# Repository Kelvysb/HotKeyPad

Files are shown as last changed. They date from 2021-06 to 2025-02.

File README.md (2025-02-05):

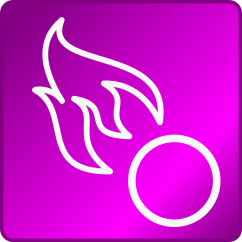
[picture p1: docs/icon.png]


# HotKeyPad

Arduino based hot keys programmable mini keyboard.

Arduino **Mega32U4** based.

# 

# Serial commands

* Ack 
  - Command = A
* Set a command 
  - Command = S\<pos\>\<command\>
  - pos = 48 to 59 (11 buttons, ASCII {0,1,2,3,4,5,6,7,8,9,:,;})
* Read command list 
  - command = R
* Clear memmory 
  - command = C

# Command format

```
<mode><hold time><delay time><ctrl><alt><shift><gui>[<key list>]
```

* mode:
  * 48 = hold (press all keys)
  * 49 = sequence (press keys in sequence)
* hold time:
  * Time holding the key, (t * 100)ms (modifiers not included) 
  * only on sequence mode
* delay time:
  * Time between the keys, (t * 100)ms (modifiers not included) 
  * only on sequence mode
* crtl, alt, shift, and gui (modifiers)
  * 48 = not pressed
  * 49 = pressed
* key list
  * Key sequence (ASCII code)
  * In hold mode pressed all at the same time, and released when the button it's released.
  * In sequence mode press and release using hold and delay times.

## Control Keys

| KEY HEXADECIMAL | VALUE | DECIMAL VALUE |
| --- | ----- | --- |
| KEY_LEFT_CTRL | 0x80  | 128 |
| KEY_LEFT_SHIFT  | 0x81  | 129 |
| KEY_LEFT_ALT | 0x82  | 130 |
| KEY_LEFT_GUI | 0x83  | 131 |
| KEY_RIGHT_CTRL  | 0x84  | 132 |
| KEY_RIGHT_SHIFT | 0x85  | 133 |
| KEY_RIGHT_ALT | 0x86  | 134 |
| KEY_RIGHT_GUI | 0x87  | 135 |
| KEY_UP_ARROW | 0xDA  | 218 |
| KEY_DOWN_ARROW  | 0xD9  | 217 |
| KEY_LEFT_ARROW  | 0xD8  | 216 |
| KEY_RIGHT_ARROW | 0xD7  | 215 |
| KEY_BACKSPACE | 0xB2  | 178 |
| KEY_TAB | 0xB3  | 179 |
| KEY_RETURN | 0xB0  | 176 |
| KEY_ESC | 0xB1  | 177 |
| KEY_INSERT | 0xD1  | 209 |
| KEY_DELETE | 0xD4  | 212 |
| KEY_PAGE_UP | 0xD3  | 211 |
| KEY_PAGE_DOWN | 0xD6  | 214 |
| KEY_HOME | 0xD2  | 210 |
| KEY_END | 0xD5  | 213 |
| KEY_CAPS_LOCK | 0xC1  | 193 |
| KEY_F1 | 0xC2  | 194 |
| KEY_F2 | 0xC3  | 195 |
| KEY_F3 | 0xC4  | 196 |
| KEY_F4 | 0xC5  | 197 |
| KEY_F5 | 0xC6  | 198 |
| KEY_F6 | 0xC7  | 199 |
| KEY_F7 | 0xC8  | 200 |
| KEY_F8 | 0xC9  | 201 |
| KEY_F9 | 0xCA  | 202 |
| KEY_F10 | 0xCB  | 203 |
| KEY_F11 | 0xCC  | 204 |
| KEY_F12 | 0xCD  | 205 |
| KEY_F13 | 0xF0  | 240 |
| KEY_F14 | 0xF1  | 241 |
| KEY_F15 | 0xF2  | 242 |
| KEY_F16 | 0xF3  | 243 |
| KEY_F17 | 0xF4  | 244 |
| KEY_F18 | 0xF5  | 245 |
| KEY_F19 | 0xF6  | 246 |
| KEY_F20 | 0xF7  | 247 |
| KEY_F21 | 0xF8  | 248 |
| KEY_F22 | 0xF9  | 249 |
| KEY_F23 | 0xFA  | 250 |
| KEY_F24 | 0xFB  | 251 |

# Program

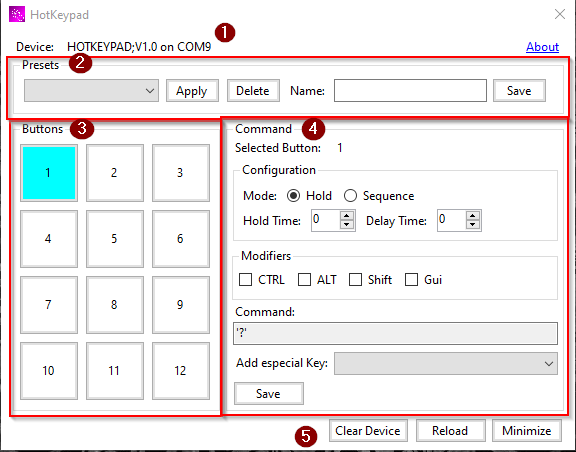
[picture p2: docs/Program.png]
Program


1. This field indicates the connected device and the port;
2. Presets:
   * Here you can save presets, when a preset it's applied, the memory of the device it's cleared and all the commands of the preset it's loaded to the device;
3. The buttons of the device, you can select they to alter it's configurations;
4. Button configuration you can set what a button will do here:
   * Mode:
     - hold, all buttons will be pressed at the same time;
     - sequence, the button will be pressed in sequence following the configured 'hold time' and 'delay time' (time to wait before press the next button);
   * Modifiers: 
     - Control, alt, Shift, and Gui (win key on windows);
   * Command:
     - Just press a key to set, and use backspace to remove a key
     - To add a especial key/command use the list bellow.
   * Save: 
     - Remember to save to record the command on the device.
5. Controls:
   * Clear Device:
     - Clear device memory;
     - Reload commands from the connected device;
     - Minimize to tray;

# Presets

* Presets are saved on `<Your Document Folder>\HotKeyPad` on '*json*' format.
* You can export presets copying them from this folder.
* You can import presets adding them to this folder.

# Casing (3D printed) Version 2.0 - Using switches

[Model on Thingiverse](https://www.thingiverse.com/thing:6915041)

3D printed Casing
3D printed Casing
3D printed Casing
3D printed Casing
3D printed Casing

# Base Circuit 2.0

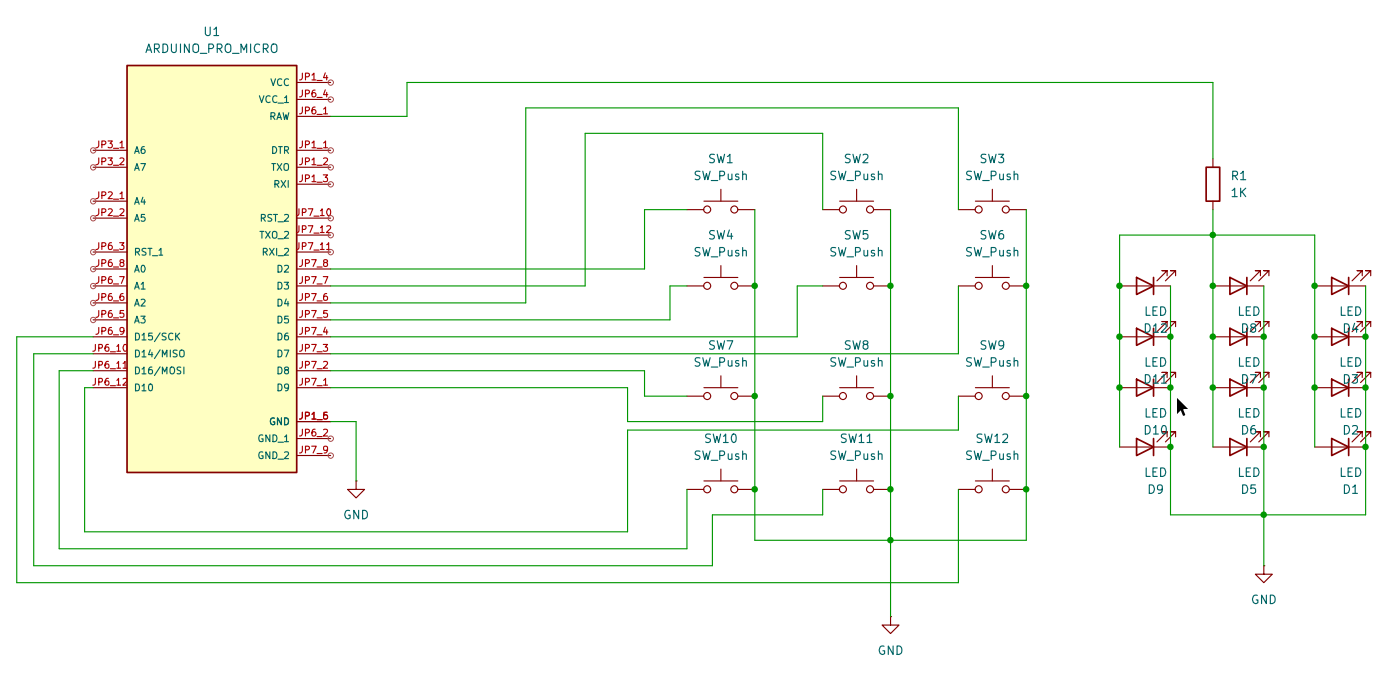
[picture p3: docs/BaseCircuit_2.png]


# Material List 2.0

- Arduino Pro Micro (Mega32U4):
  
  - [Aliexpress: Arduino pro micro](https://s.click.aliexpress.com/e/_oDuboil);

- Keypad:
  
  - 12 keyboard switchs;
    - [Aliexpress Switches](https://s.click.aliexpress.com/e/_oD1yDoz)
  - 12 Keycaps (can be printed, files included)
  - 12 3mm leds
  - 24 Stamped contacts (removed from commom stamped IC sockets)
    - [Aliexpress stamped sockets](https://s.click.aliexpress.com/e/_oBNMCW9)

- Wires for assembly;

- Soldering wire;

- USB cable;

- 4 M3 Bolts;

- 4 M3 Nuts;

- A good soldering iron;

- Patience;

# 

# Base Circuit 1.0

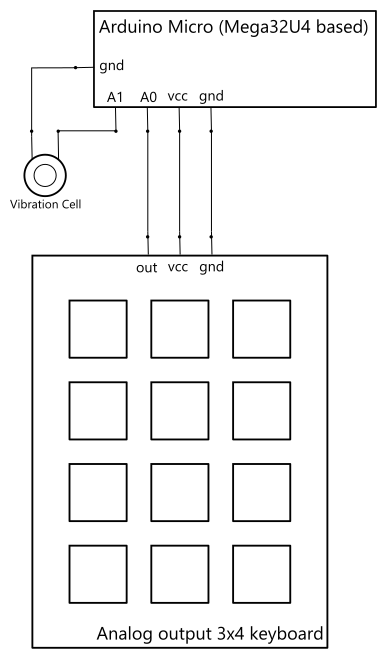
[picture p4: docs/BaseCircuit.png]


- Vibration cell optional.
- Keyboard can be of any kind, only need to update '*readButton*' method on Arduino code (*\Arduino\HotKeyPad\HotKeyPad.ino*)

# Casing (3D printed) Version 1.0 - Using resistive 3x4 Keypad

[Model on Thingiverse](https://www.thingiverse.com/thing:5168905)

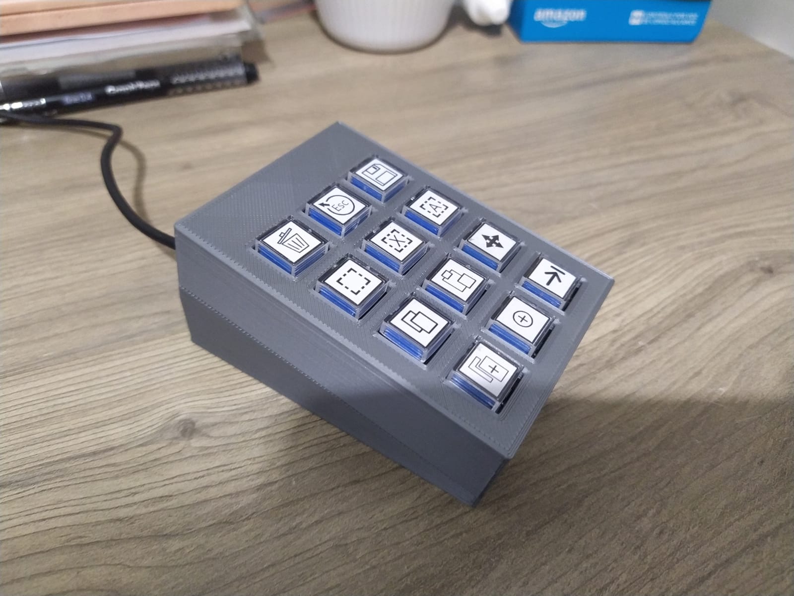
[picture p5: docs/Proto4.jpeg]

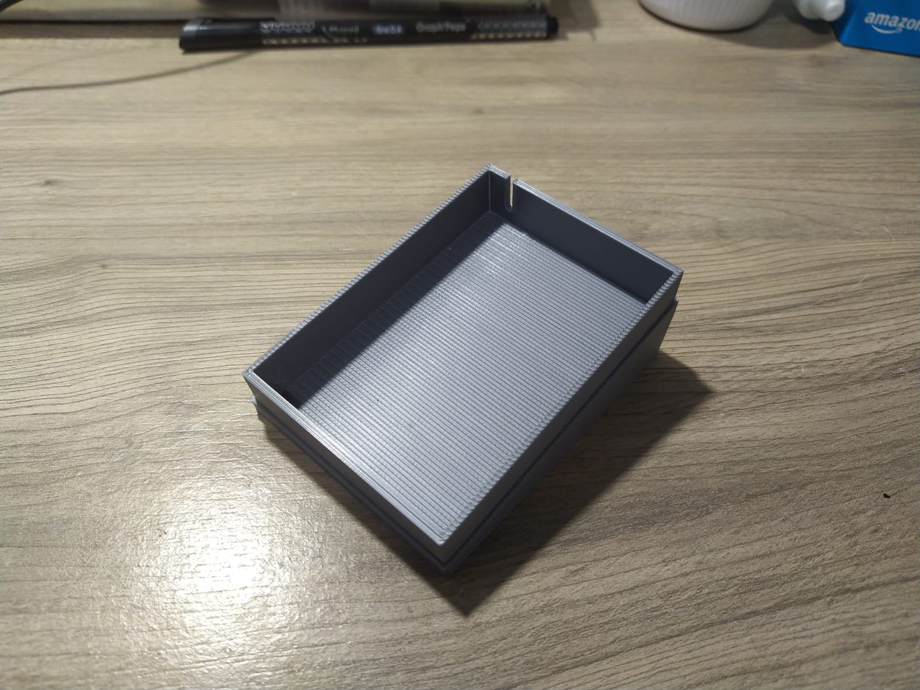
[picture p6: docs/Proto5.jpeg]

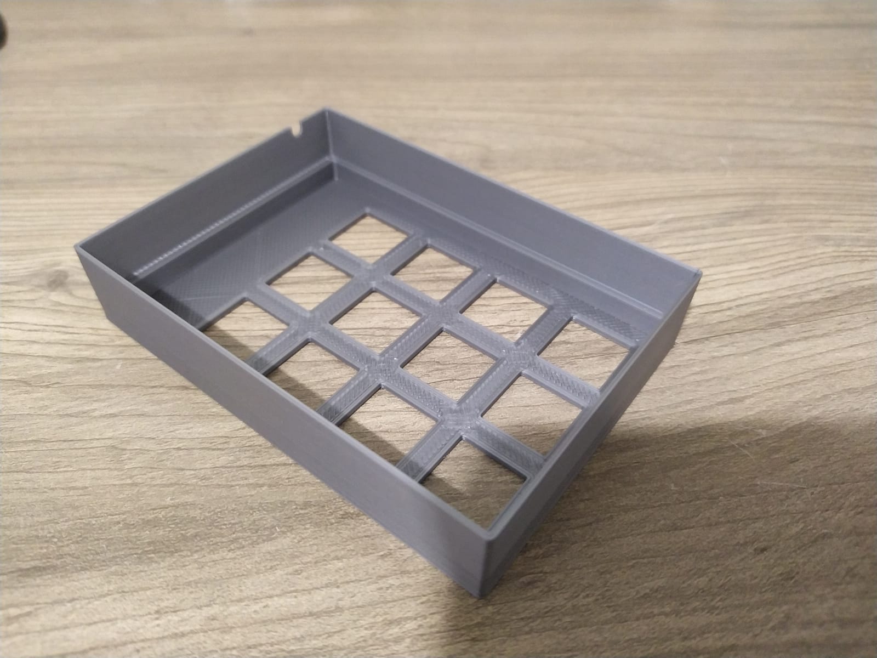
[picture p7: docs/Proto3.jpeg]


# Material List 1.0

* Arduino Pro Micro (Mega32U4):
  
  - [Aliexpress: Arduino pro micro](https://s.click.aliexpress.com/e/_oDuboil);

* Keypad:
  
  - Can be of any kind, or with some soldering skills you can use mechanical keyboard switchs;
  - [Aliexpress: mechanical switchs](https://s.click.aliexpress.com/e/_oD1yDoz);
  - [Aliexpress: Relegendable Keycaps](https://s.click.aliexpress.com/e/_om7lIPf);

* Optional vibration motor (Vibration cell)
  
  - [Aliexpress: Vibration motor](https://s.click.aliexpress.com/e/_oo2dn4d);

* PCB
  
  - In the example I used prototype PCB, but you can make your own;

* 3 pin female PCB connector

* Wires for assembly;

* Soldering wire;

* Micro USB cable;

* Some bolts and spacers;
  
  - [Aliexpress: Spacers](https://s.click.aliexpress.com/e/_oFxN3eD);

* A good soldering iron;

* Patience;

# Prototype (version 0.1)

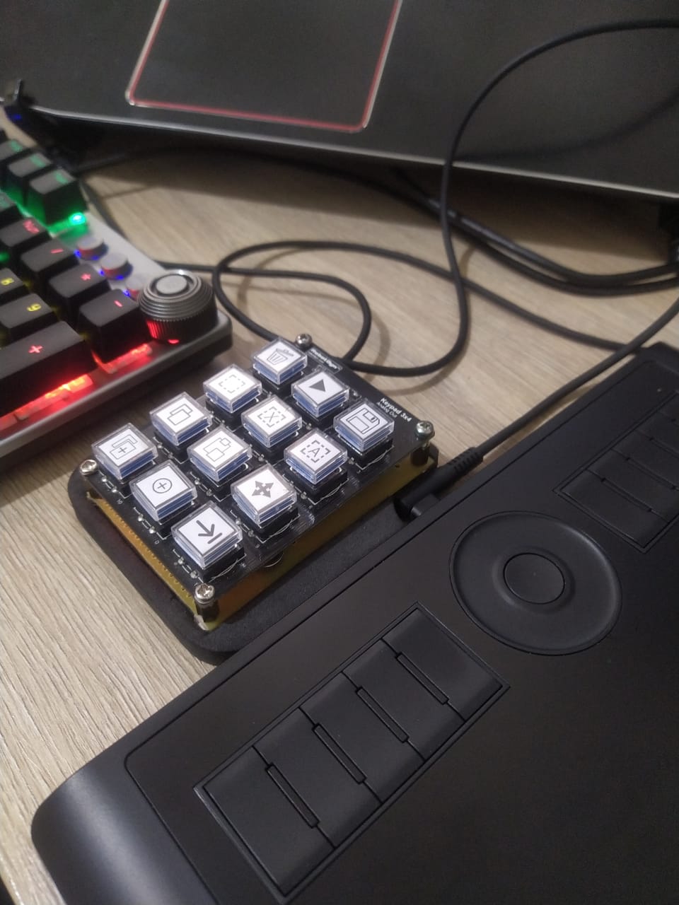
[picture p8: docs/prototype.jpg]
Prototype


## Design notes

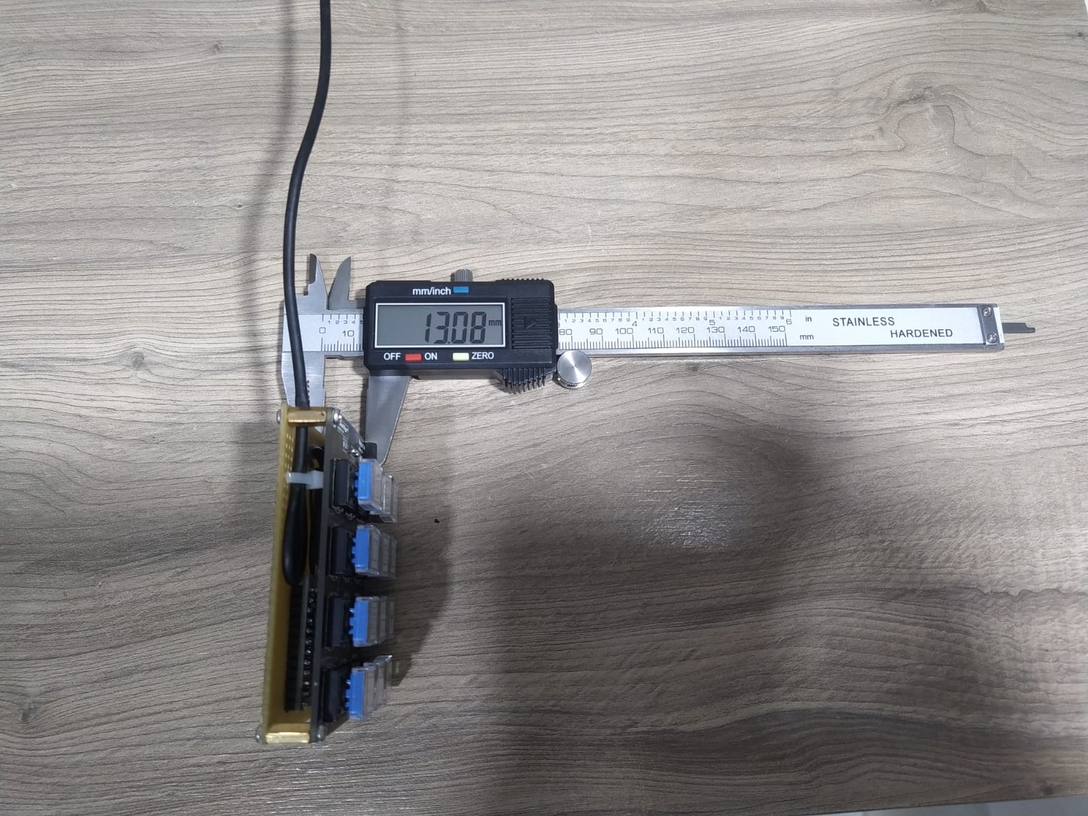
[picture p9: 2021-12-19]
docs/Proto6.jpeg

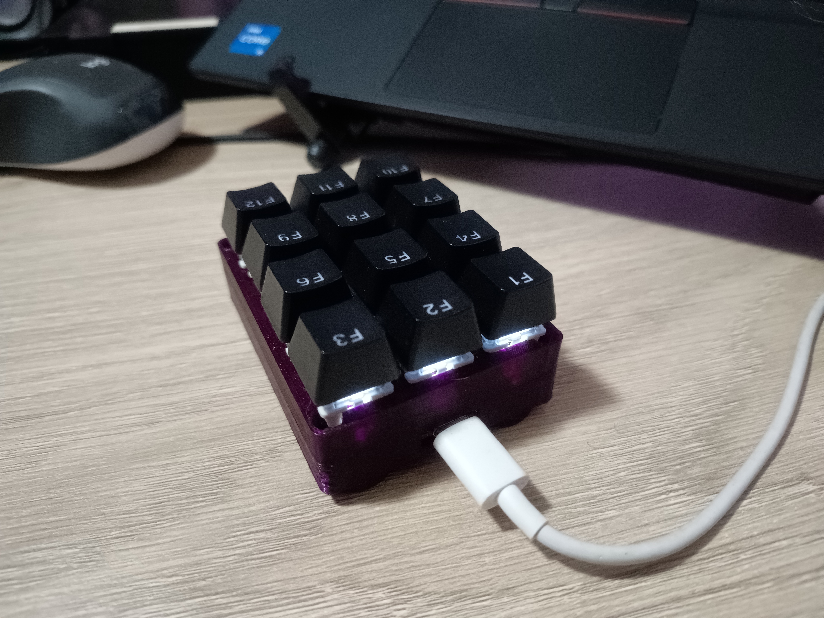
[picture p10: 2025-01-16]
docs/HotKeys5.jpg

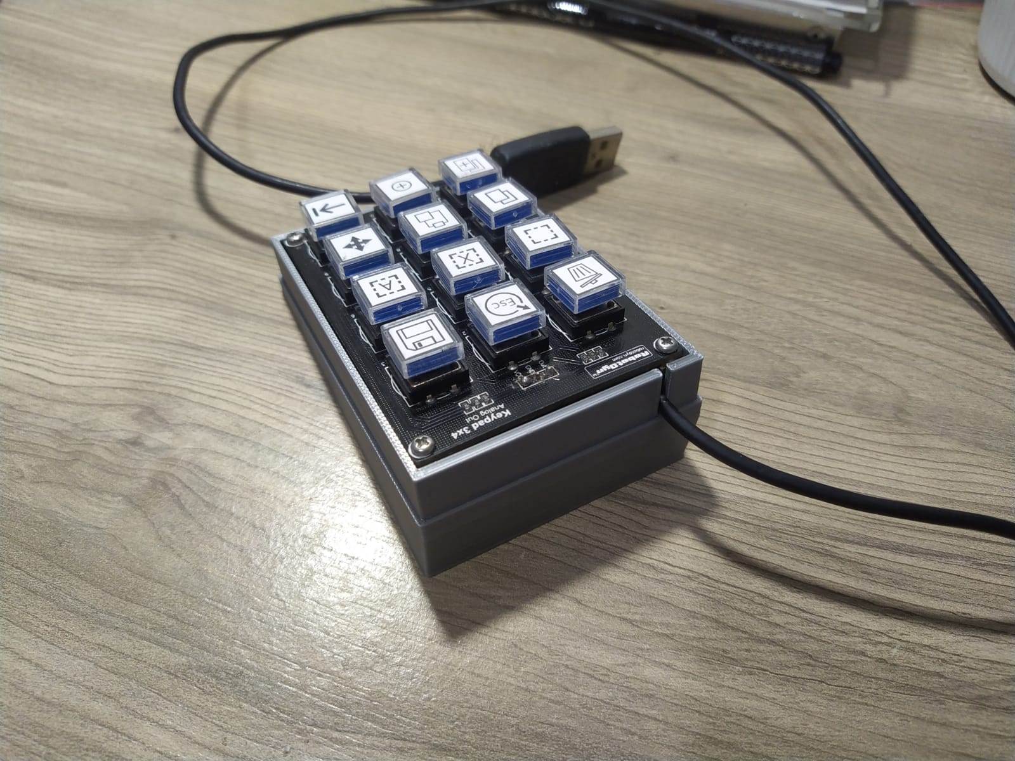
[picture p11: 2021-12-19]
docs/Proto8.jpeg

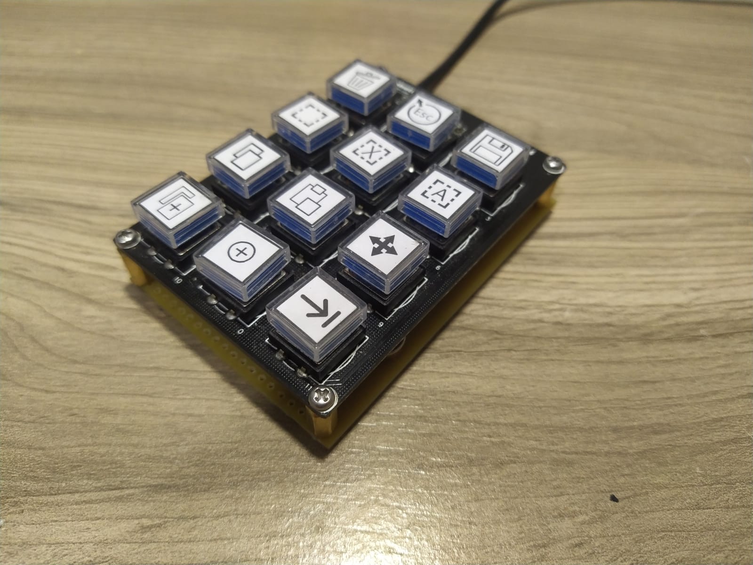
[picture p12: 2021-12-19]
docs/Proto9.jpeg

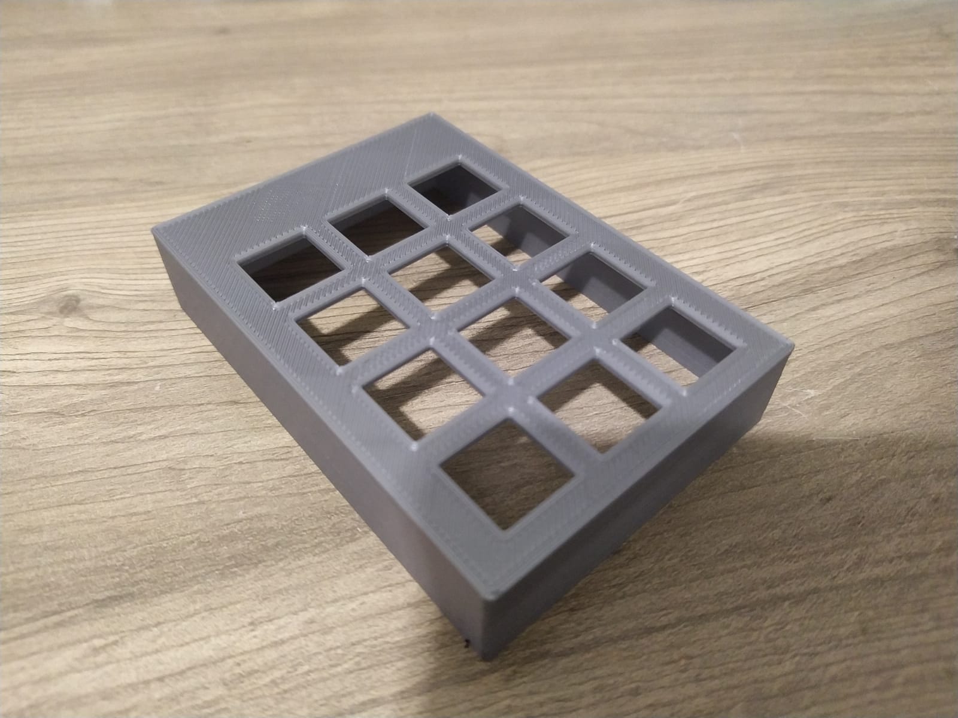
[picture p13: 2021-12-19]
docs/Proto2.jpeg

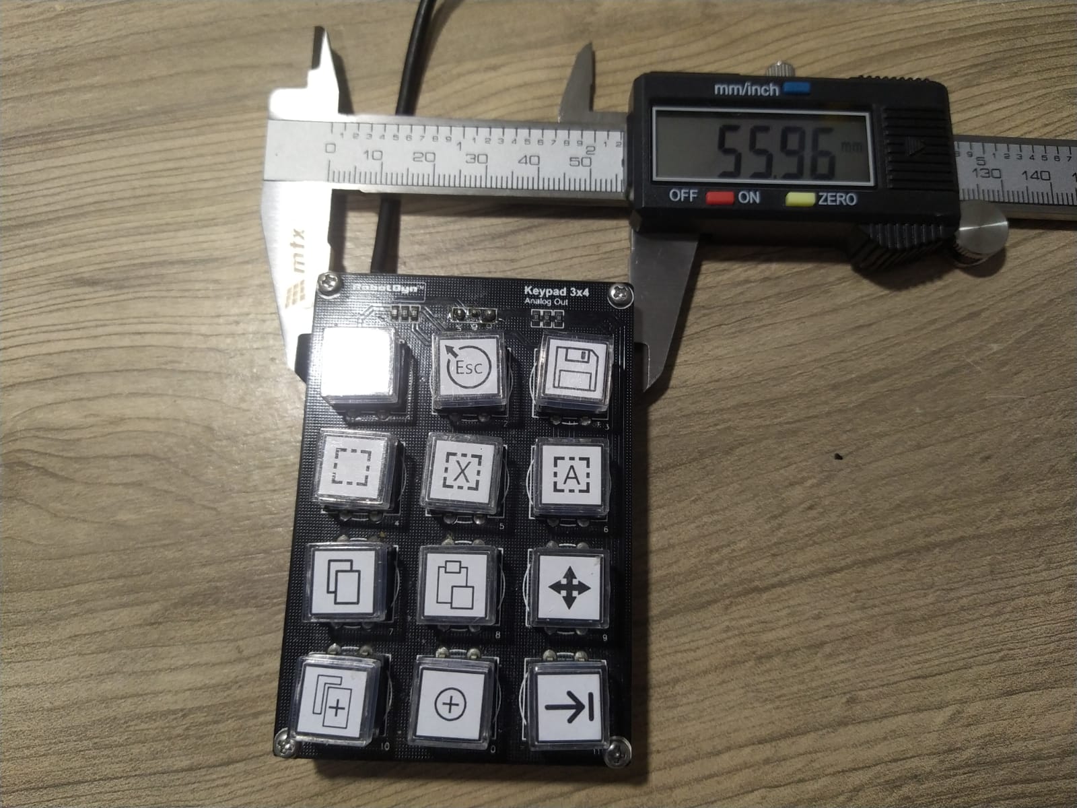
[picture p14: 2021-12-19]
docs/Proto7.jpeg

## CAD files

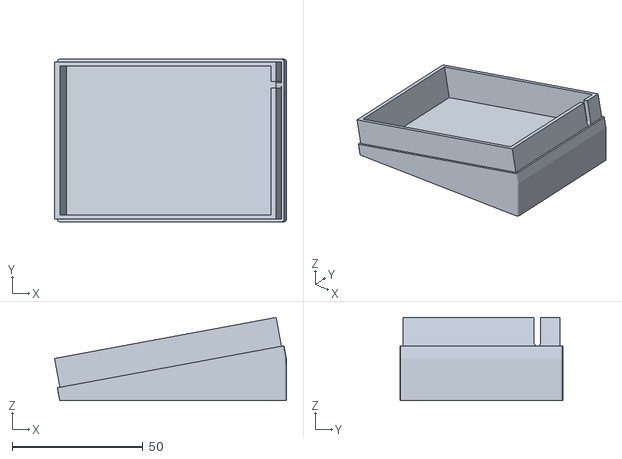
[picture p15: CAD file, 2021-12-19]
Casing/10/SideKeys_Base.stl
88.6 x 62.0 x 31.7

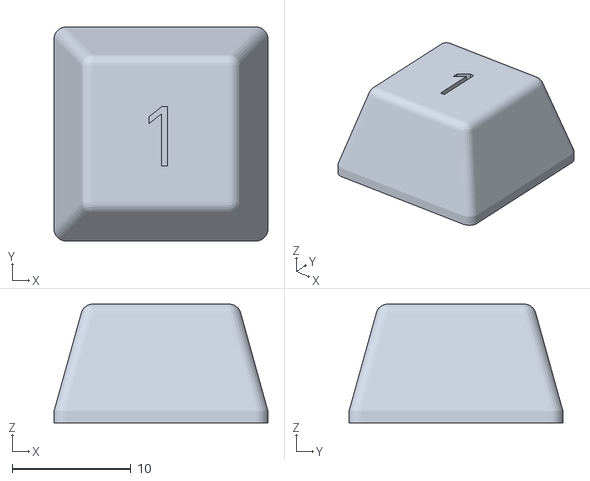
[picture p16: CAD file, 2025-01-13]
Casing/20/HotKeys2-Cap_1.stl
18.0 x 18.0 x 10.0

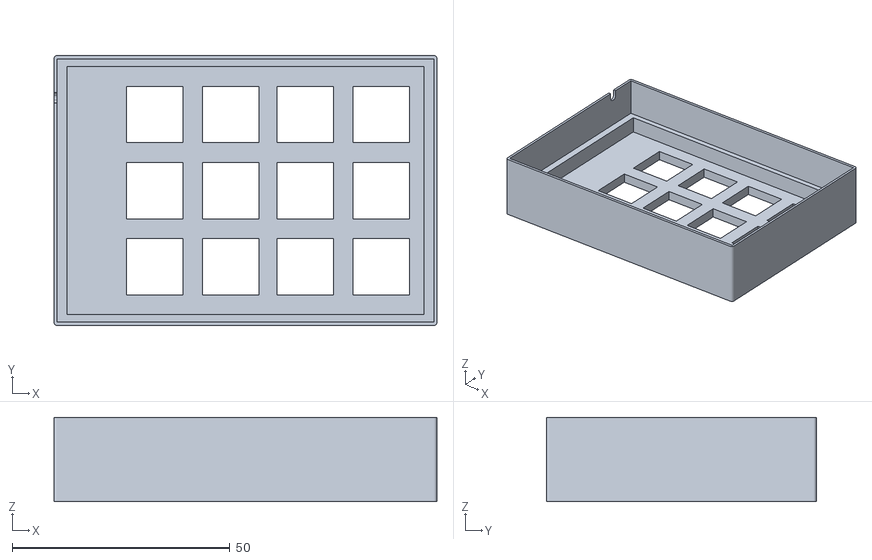
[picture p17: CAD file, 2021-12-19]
Casing/10/SideKeys_Cap.stl
88.0 x 62.0 x 19.4

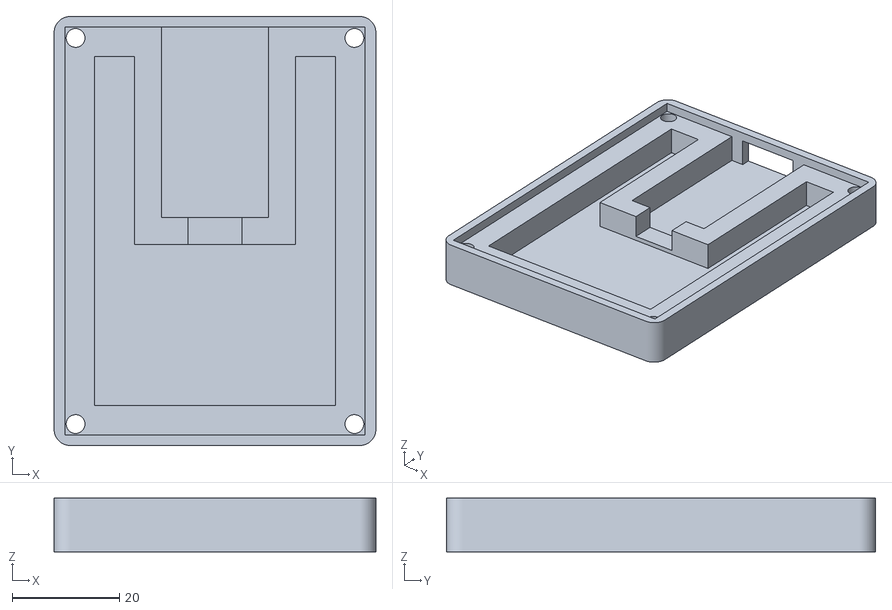
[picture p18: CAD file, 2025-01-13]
Casing/20/HotKeys2-Base.stl
60.0 x 80.0 x 10.0

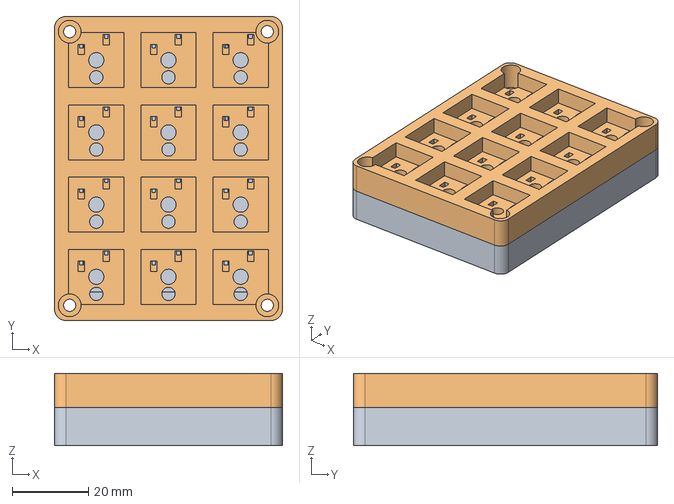
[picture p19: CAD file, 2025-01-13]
Casing/20/HotKeys2.FCStd
60.0 x 80.0 x 19.0 mm
Base
CorpoLed

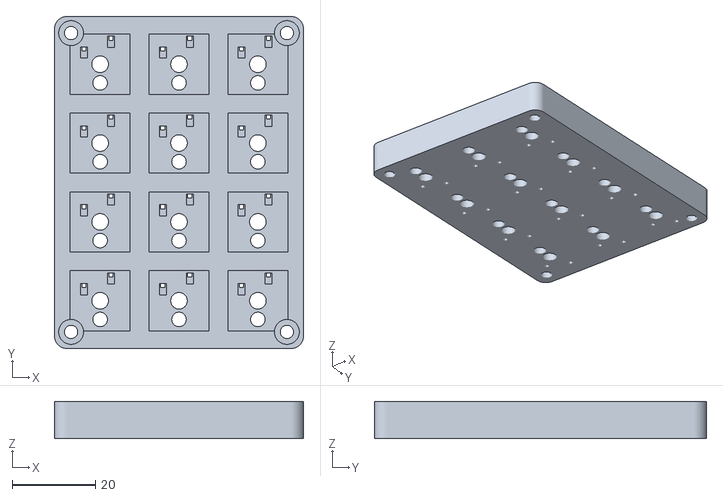
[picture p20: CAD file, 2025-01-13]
Casing/20/HotKeys2-CorpoLed.stl
60.0 x 80.0 x 9.00

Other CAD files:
Casing/20/HotKeys2-Cap_2.stl
Casing/20/HotKeys2-Cap_C.stl
Casing/20/HotKeys2-Cap_3.stl
Casing/20/HotKeys2-Cap_6.stl
Casing/20/HotKeys2-Cap_7.stl
Casing/20/HotKeys2-Cap_8.stl
Casing/20/HotKeys2-Cap_B.stl
Casing/20/HotKeys2-Cap_4.stl
Casing/20/HotKeys2-Cap_A.stl
Casing/20/HotKeys2-Cap_9.stl
Casing/20/HotKeys2-Cap_5.stl
Casing/20/HotKeys2-Corpo.stl
Casing/10/SideKeys.blend

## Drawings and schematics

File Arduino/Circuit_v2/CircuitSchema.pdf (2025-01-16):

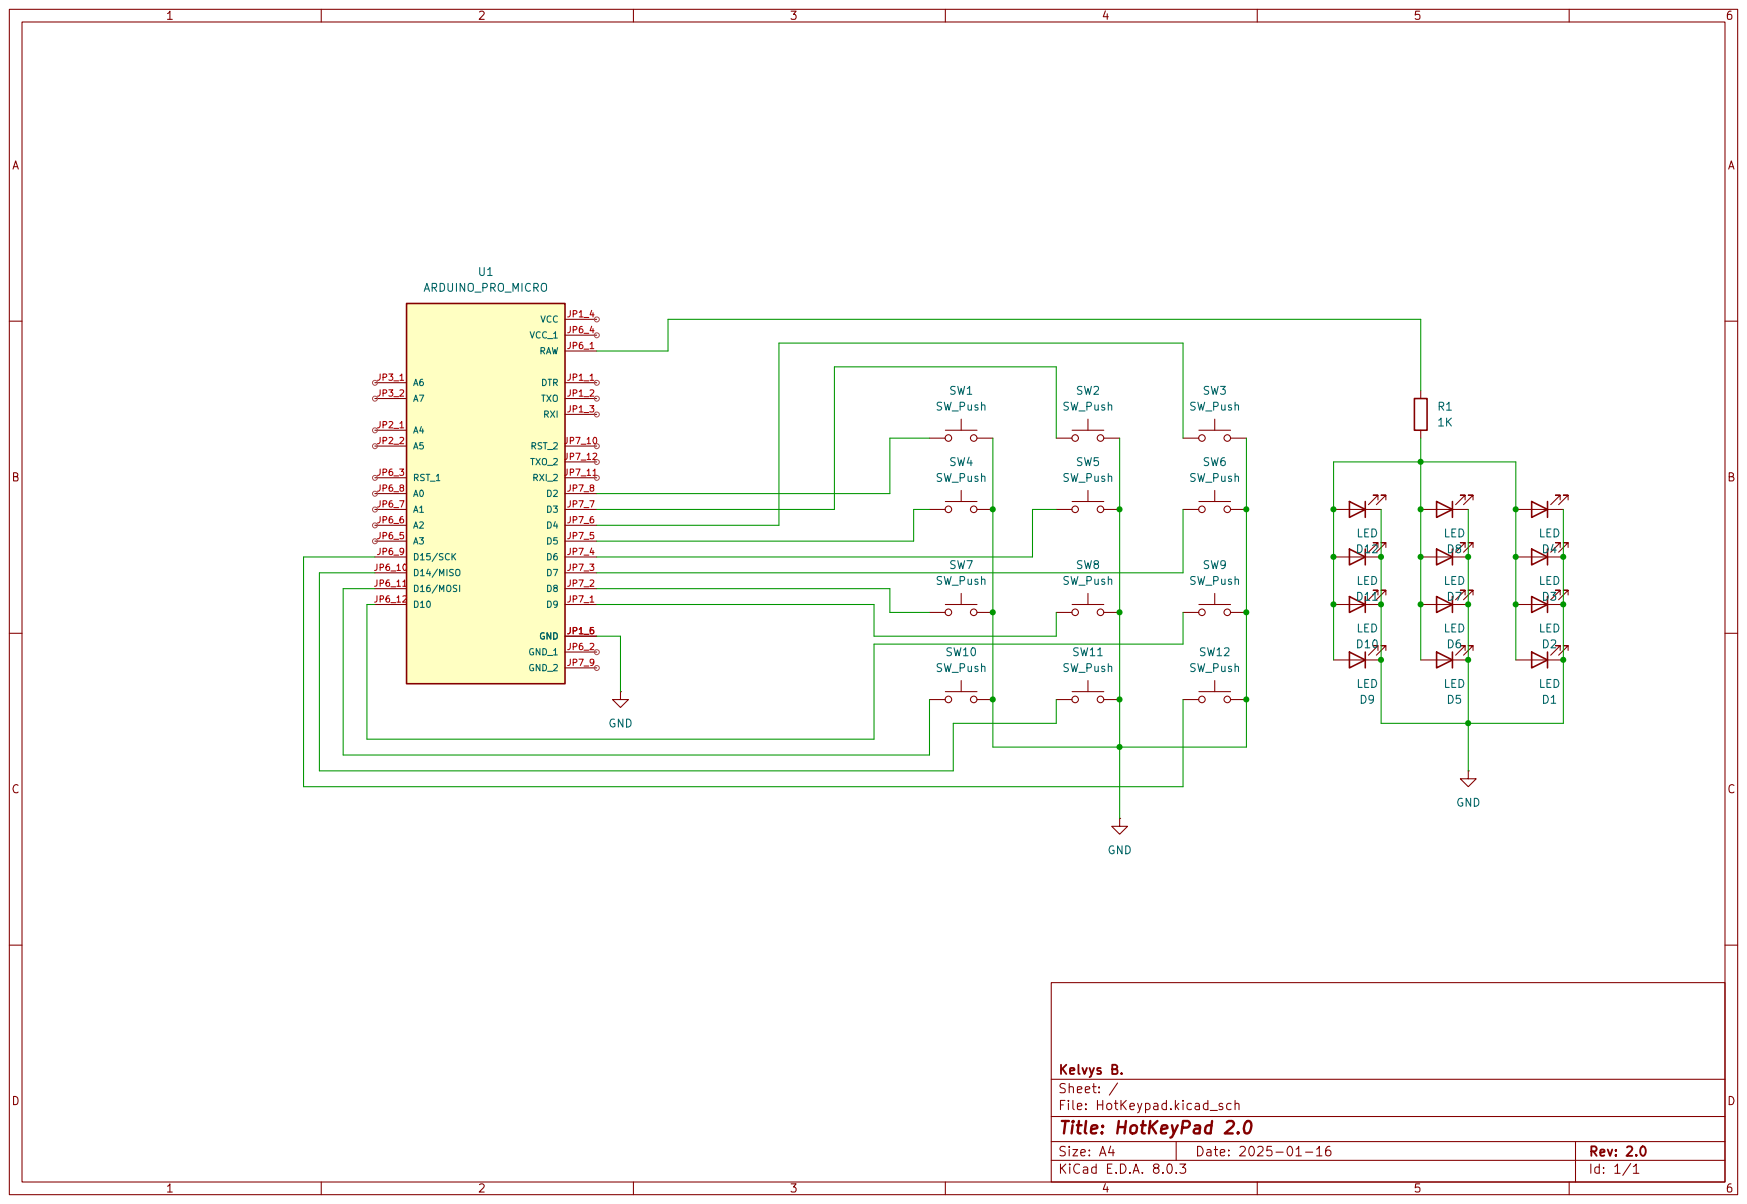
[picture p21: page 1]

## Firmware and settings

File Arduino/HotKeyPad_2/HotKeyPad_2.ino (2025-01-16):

#include <EEPROM.h>
#include <Keyboard.h>

const String VER = "HOTKEYPAD;V2.0";
const int BLOCK_SIZE = 85;
const int DEFAULT_DELAY = 10;
const int NUM_OFFSET = 48;
const int CFALSE = 48;
const int CTRUE = 49;
const int CTRL = 128;
const int ALT = 130;
const int SHIFT = 129;
const int GUI = 131;
const int NUL = 0;
const int ACK = 65;
const int READ = 82;
const int SET = 83;
const int CLEAR = 67;
const int VIB = A1;

const int BUTTON_1 = 15;
const int BUTTON_2 = 14;
const int BUTTON_3 = 16;
const int BUTTON_4 = 10;
const int BUTTON_5 = 9;
const int BUTTON_6 = 8;
const int BUTTON_7 = 7;
const int BUTTON_8 = 6;
const int BUTTON_9 = 5;
const int BUTTON_10 = 4;
const int BUTTON_11 = 3;
const int BUTTON_12 = 2;

int holdKey = 0;
bool buttonDown = false;

void setup() { 
  Serial.begin(9600);    
  pinMode(BUTTON_1, INPUT);
  pinMode(BUTTON_2, INPUT);
  pinMode(BUTTON_3, INPUT);
  pinMode(BUTTON_4, INPUT);
  pinMode(BUTTON_5, INPUT);
  pinMode(BUTTON_6, INPUT);
  pinMode(BUTTON_7, INPUT);
  pinMode(BUTTON_8, INPUT);
  pinMode(BUTTON_9, INPUT);
  pinMode(BUTTON_10, INPUT);
  pinMode(BUTTON_11, INPUT);
  pinMode(BUTTON_12, INPUT);
  digitalWrite(BUTTON_1, HIGH);
  digitalWrite(BUTTON_2, HIGH);
  digitalWrite(BUTTON_3, HIGH);
  digitalWrite(BUTTON_4, HIGH);
  digitalWrite(BUTTON_5, HIGH);
  digitalWrite(BUTTON_6, HIGH);
  digitalWrite(BUTTON_7, HIGH);
  digitalWrite(BUTTON_8, HIGH);
  digitalWrite(BUTTON_9, HIGH);
  digitalWrite(BUTTON_10, HIGH);
  digitalWrite(BUTTON_11, HIGH);
  digitalWrite(BUTTON_12, HIGH);
}

void loop() {

  char serialCommand[BLOCK_SIZE+1];
  
  if (Serial.available() > 0) 
  {    
    Serial.readBytes(serialCommand, BLOCK_SIZE+1);
    if(serialCommand[0] == ACK)
    {
      Serial.println(VER);
    }
    if(serialCommand[0] == READ)
    {
      readAllCommands();
    }
    if(serialCommand[0] == SET)
    {
      setCommand(serialCommand);
    }
    if(serialCommand[0] == CLEAR)
    {
      clearCommands();
    }
  }
      
  int currentKey = readButton();
  
  if(currentKey != 0 && holdKey == 0)
  {    
    holdKey = currentKey;
    Serial.print("D:");
    Serial.println(currentKey);
    Keyboard.begin();
    execCommand(currentKey-1);
    analogWrite(VIB, 512);
    delay(100);
    analogWrite(VIB, 0);
  } else if(currentKey == 0 && holdKey != 0)
  {    
    Keyboard.releaseAll();   
    Keyboard.end();
    Serial.print("U:");
    Serial.println(holdKey);    
    holdKey = 0;
  }
}

void execCommand(int key)
{
  char command[BLOCK_SIZE];
  readCommand(command, key);
  
  bool sequenceMode = command[0] == CTRUE;
  int pressTime = (command[1] - NUM_OFFSET) * 100;
  int betweenTime = (command[2] - NUM_OFFSET) * 100;
  bool ctrl = command[3] == CTRUE;
  bool alt = command[4] == CTRUE;
  bool shift = command[5] == CTRUE;
  bool gui = command[6] == CTRUE;

  if(pressTime == 0)
  {
    pressTime = DEFAULT_DELAY;
  }

  if(betweenTime == 0)
  {
    betweenTime = DEFAULT_DELAY;
  }

  if(ctrl)
  {
    Keyboard.press(CTRL);  
  }
  if(alt)
  {
    Keyboard.press(ALT);  
  }
  if(shift)
  {
    Keyboard.press(SHIFT);  
  }
  if(gui)
  {
    Keyboard.press(GUI);  
  }

  for(int i = 7; i < BLOCK_SIZE; i++)
  {
    if(command[i] == NUL)
    {
      break;
    }
    if(!sequenceMode)
    {      
      Keyboard.press(command[i]);
    }else
    {      
      Keyboard.press(command[i]);
      delay(pressTime);
      Keyboard.release(command[i]);
      delay(betweenTime);
    }    
  }   
}

void readCommand(char (& command)[BLOCK_SIZE], int key)
{
  int pos = key * BLOCK_SIZE;
  int index = 0;
  
  for(int i = pos; i < pos + BLOCK_SIZE; i++)
  {
     command[index] = EEPROM.read(i);
     index++;
  }
}

void setCommand(char serialCommand[BLOCK_SIZE])
{  
  if(validate(serialCommand))
  {
    int key = serialCommand[1] - NUM_OFFSET;  
    int pos = key * BLOCK_SIZE;    
    bool fill = false;
    int index = 2;
    for(int i = pos; i < pos + BLOCK_SIZE; i++)
    {              
      if(!fill){
        fill = serialCommand[index] == NUL;
        EEPROM.write(i, serialCommand[index]);
        index++;       
      }else{      
        EEPROM.write(i, 0);   
      }     
    }
    Serial.println("OK");
    Serial.println("POS-" + String(pos));
  }else
  {
    Serial.println("FAIL");
  }  
}

bool validate(char serialCommand[BLOCK_SIZE])
{  
  if(serialCommand[1] - NUM_OFFSET < 0 || serialCommand[1] - NUM_OFFSET > 11)
  {
    Serial.println("ERR1");
    return false;  
  }
  if(serialCommand[2] != CTRUE && serialCommand[2] != CFALSE)
  {
    Serial.println("ERR2");
    return false;  
  }
  if(serialCommand[3] - NUM_OFFSET < 0 || serialCommand[3] - NUM_OFFSET > 9)
  {
    Serial.println("ERR3");
    return false;  
  }
  if(serialCommand[4] - NUM_OFFSET < 0 || serialCommand[4] - NUM_OFFSET > 9)
  {
    Serial.println("ERR4");
    return false;  
  }
  for(int i = 5; i <= 7; i++ )
  {
    if(serialCommand[i] != CTRUE && serialCommand[i] != CFALSE)
    {     
      Serial.println("ERR5X");
      return false;
    }
  }  
  return true;
}

void readAllCommands()
{
  char result[BLOCK_SIZE];
  int com = 0;
  for(int i = 0; i < (BLOCK_SIZE * 12); i = i + BLOCK_SIZE)
  {
    Serial.print("C:");
    Serial.print(com);
    Serial.print(":");
    for(int index = i; index < i + BLOCK_SIZE; index++)
    {
      result[i] =  EEPROM.read(index);
      Serial.print(result[i]);
    }
    Serial.println("");
    com++;
  } 
}

void clearCommands()
{
  for(int i = 0; i < EEPROM.length(); i++)
  {  
    EEPROM.write(i, 0);
  }
  Serial.println("OK");
}

int readButton(){
  int result = 0;
  if(!digitalRead(BUTTON_1)){
    result = 1;
  }
  if(!digitalRead(BUTTON_2)){
    result = 2;
  }
  if(!digitalRead(BUTTON_3)){
    result = 3;
  }
  if(!digitalRead(BUTTON_4)){
    result = 4;
  }
  if(!digitalRead(BUTTON_5)){
    result = 5;
  }
  if(!digitalRead(BUTTON_6)){
    result = 6;
  }
  if(!digitalRead(BUTTON_7)){
    result = 7;
  }
  if(!digitalRead(BUTTON_8)){
    result = 8;
  }
  if(!digitalRead(BUTTON_9)){
    result = 9;
  }
  if(!digitalRead(BUTTON_10)){
    result = 10;
  }
  if(!digitalRead(BUTTON_11)){
    result = 11;
  }  
  if(!digitalRead(BUTTON_12)){
    result = 12;
  }      
  return result;
}

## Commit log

2021-06-05 Added documentation. Added circuit schema. Added Preset functionality.
2021-06-06 Update readme with material list
2021-12-19 Added 3D printed casing
2025-01-13 v2 initial
    [HotKeys2-Base.stl, HotKeys2-Cap_1.stl, HotKeys2-Cap_2.stl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]
2025-01-16 added docs for version 2.0
    [HotKeypad.kicad_pcb, HotKeypad.kicad_sch]
